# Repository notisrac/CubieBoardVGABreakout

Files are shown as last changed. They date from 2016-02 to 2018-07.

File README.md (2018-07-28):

# VGA breakout board for Cubieboard

PCB for the vga output of the cubieboard: [https://github.com/cubieplayer/Cubian/wiki/VGA-output](https://github.com/cubieplayer/Cubian/wiki/VGA-output)

## BOM
* 1x VGA connector
* 2x BAT54s Shottky diodes (note: you need the "s" version)
* 3x 75ohm resistor
* 1x 74ACT08D (note: you need the ACT version for its speed)
* 1x 100nF capacitor
* Pin headers

Analytics (https://github.com/igrigorik/ga-beacon)

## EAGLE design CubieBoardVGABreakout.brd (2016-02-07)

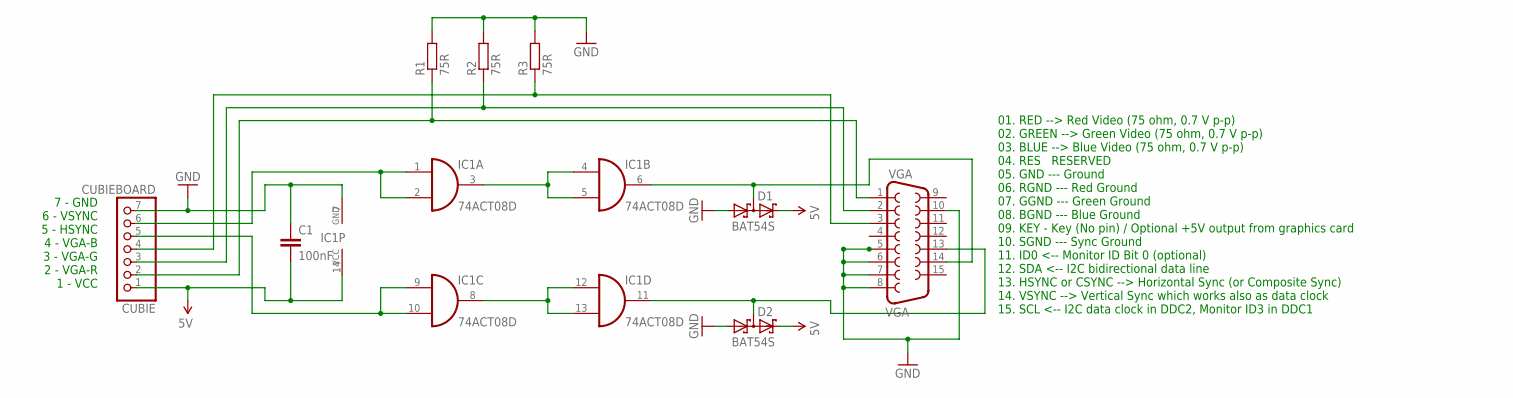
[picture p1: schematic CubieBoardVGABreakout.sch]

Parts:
C1: 100nF; 0805
CUBIE: CUBIEBOARD; 1X07
D1, D2: BAT54S; SOT23
IC1: 74ACT08D; SO14
R1, R2, R3: 75R; 0204V
VGA: VGA; HDF15H

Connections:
5V: C1.2, CUBIE.1, D1.2 (C2), D2.2 (C2), IC1.14 (VCC)
GND: C1.1, CUBIE.7, D1.1 (A1), D2.1 (A1), IC1.7 (GND), R1.2, R2.2, R3.2, VGA.5, VGA.6, VGA.7, VGA.8, VGA.10
unnamed: CUBIE.6, IC1.1 (I0), IC1.2 (I1)
unnamed: CUBIE.5, IC1.9 (I0), IC1.10 (I1)
unnamed: IC1.3 (O), IC1.4 (I0), IC1.5 (I1)
unnamed: IC1.8 (O), IC1.12 (I0), IC1.13 (I1)
unnamed: D2.3 (C1A2), IC1.11 (O), VGA.13
unnamed: D1.3 (C1A2), IC1.6 (O), VGA.14
VGA-B: CUBIE.4, R3.1, VGA.3
VGA-G: CUBIE.3, R2.1, VGA.2
VGA-R: CUBIE.2, R1.1, VGA.1

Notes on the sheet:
7 - GND 6 - VSYNC 5 - HSYNC 4 - VGA-B 3 - VGA-G 2 - VGA-R 1 - VCC
01. RED --> Red Video (75 ohm, 0.7 V p-p) 02. GREEN --> Green Video (75 ohm, 0.7 V p-p) 03. BLUE --> Blue Video (75 ohm, 0.7 V p-p) 04. RES RESERVED 05. GND --- Ground 06. RGND --- Red Ground 07. GGND --- Green Ground 08. BGND --- Blue Ground 09. KEY - Key (No pin) / Optional +5V output from graphi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

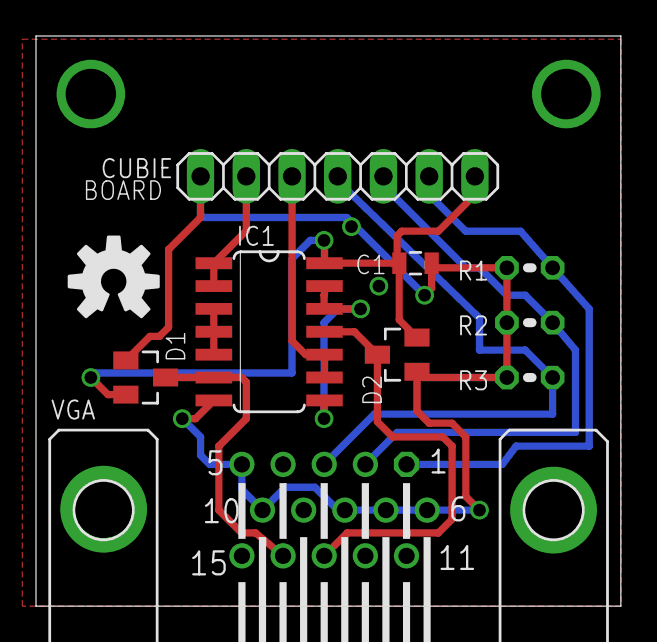
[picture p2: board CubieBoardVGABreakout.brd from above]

Board: 2 copper layers, 32.5 x 31.7 mm, 10 parts (0 on the bottom side), 11 nets.

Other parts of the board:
U$1: OSHW-LOGO-M

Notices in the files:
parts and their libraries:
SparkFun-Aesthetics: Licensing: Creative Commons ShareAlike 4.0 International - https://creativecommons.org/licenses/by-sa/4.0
